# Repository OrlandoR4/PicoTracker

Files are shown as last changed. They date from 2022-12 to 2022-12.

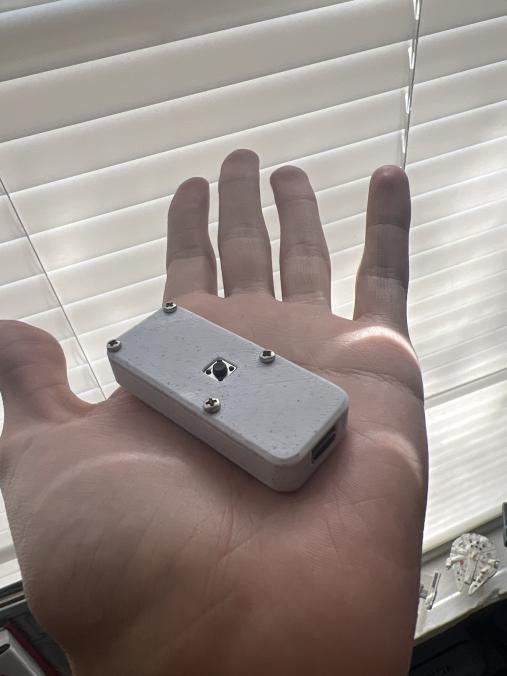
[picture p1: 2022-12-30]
example/Built device.jpg

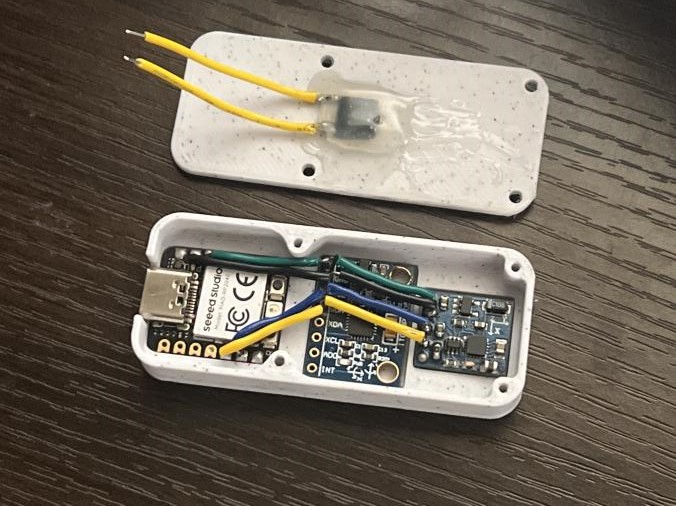
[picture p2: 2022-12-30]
example/Internals.jpg

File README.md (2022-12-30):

### VERSION 2.0

# HATIRE-ENABLED HEAD TRACKER FOR OPENTRACK

This program uses the **XIAO RP2040 microcontroller**,
**MPU6050** Inertial Measurement Unit, and the **QMC5883L**
magnetometer to estimate orientation and output HATIRE
data for OpenTrack

Uses a single push button for calibration and resetting (with an internal pull up from the microcontroller)

Customize the code as its fit to you and install the necessary dependencies

If the sensors or microcontroller above aren't being used
major code modification will be necessary, please refer to the comments below

***

### For the orientation to work

**Configure your vectors like this (Right Hand Rule):**

(X, Y, Z) = Roll Pitch Yaw

X : Forwards,
Y : Rightwards,
Z : Downwards
***
## USAGE

**IN-GAME:**

* Press the button to reset the euler angles, do this once
before as you play and as you see fit

**CALIBRATION:**

* Place the device where you intend to use it, for example your headphones
* Ensure the device is square and aligned with your vectors, X or FORWARDS has to your monitor and Z should be pointing DOWN

* The device is sensitive to magnetic fields and metal, so make sure you calibrate in the same conditions and position that you will be when playing

* For these first steps ensure the device is still, DO NOT ROTATE OR MOVE IT

* To calibrate the device hold the button as you connect the USB cable

* The LED will flash quickly as it calibrates the gyroscope

* Then slower as it calibrates the accelerometers

* When the LED turns off or partially off, its time to calibrate the magnetometer
  
* You can now move the device, spin the device around on ALL AXES, pretend to paint a sphere from the inside while you roll the device as well

The calibration settings will be stored on the EEPROM of your microcontroller so no new calibration has to be done every time you plug in the device

The device will slowly blink the LED when the calibration is done
You can now use the device with HATIRE and OpenTrack

Configure the axes, mappings, and filter settings as you see fit

If the raw sensor data on OpenTrack seems erroneous or undersirable,
or you set up the device on new headphones or similar,
please re-do the calibration as many times as needed

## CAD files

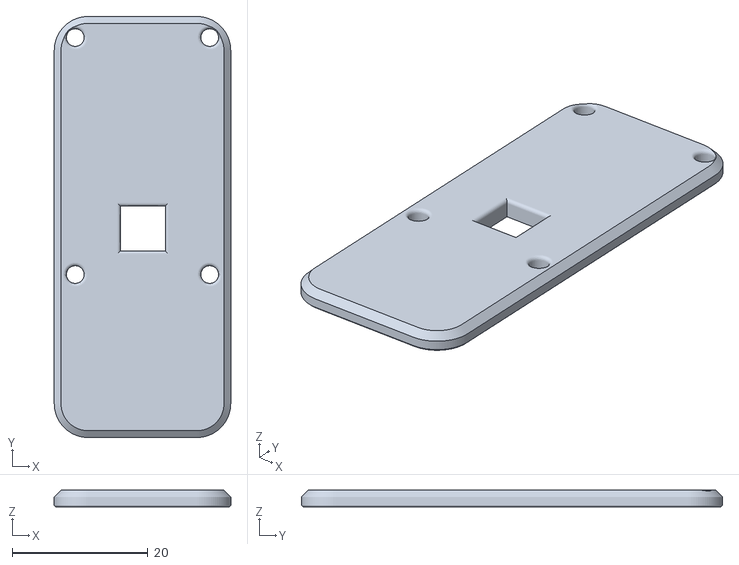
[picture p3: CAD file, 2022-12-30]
prints/Top.stl
26.0 x 62.0 x 2.50

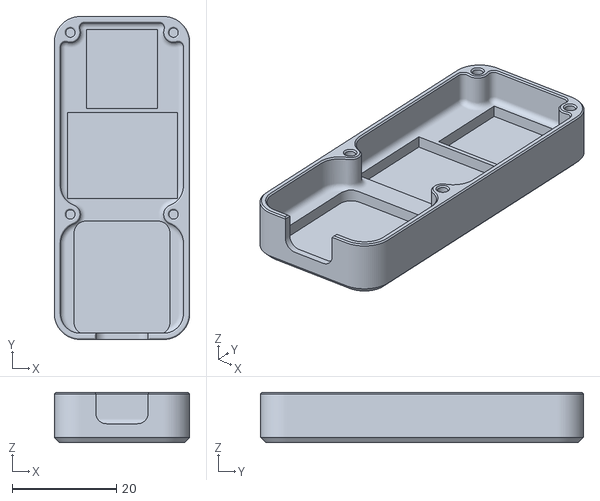
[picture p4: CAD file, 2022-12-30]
prints/Base.stl
26.0 x 62.0 x 9.60

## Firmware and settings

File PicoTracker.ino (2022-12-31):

/*
 * #################################
 * HATIRE HEAD TRACKER FOR OPENTRACK
 * #################################
 * 
 * This program uses the Rpi Pico microcontroller,
 * MPU6050 Inertial Measurement Unit, and the QMC5883L
 * magnetometer to estimate orientation and output HATIRE
 * data for OpenTrack
 * 
 * Customize the code as its fit to you and install the necessary dependencies
 * 
 * If the sensors or microcontroller above aren't being used
 * major code modification will be necessary, please refer to the comments below
 * 
 * LICENSE
 * 
 * O. Rangel Morales
 * (GitHub: OrlandoR4)
 * MIT license, all text above must be included in any redistribution
 */

#include <Arduino.h>

#include <Wire.h>
#include <EEPROM.h>
#include "Quaternion.h"

#define Wire Wire1

#include "QMC5883LCompass.h"
#include <Adafruit_Sensor.h>
#include <Adafruit_MPU6050.h>

// Inertial Measurements
Vector3 acceleration_body;
Vector3 angular_velocity;
Vector3 magnetic_flux;

// Orientation
Quaternion true_orientation;
Quaternion offset_quaternion;
Quaternion orientation;

Vector3 euler_angles;
Vector3 acceleration_inertial;

// Calibration Variables
Vector3 offset_angular_velocity;
Vector3 offset_acceleration_body;
Vector3 offset_magnetic_flux;
Vector3 scalar_magnetic_flux(1, 1, 1);

// Orientation Filter
const float orientation_filter_frequency = 200;
const float accelerometer_correction_gain = 0.01;
const float magnetometer_correction_gain = 0.01;

// EEPROM per 32 Bytes
// 0 -> 2  : gyroscopic offsets
// 3 -> 5  : acceleration offsets
// 6 -> 8  : magnetic offsets
// 9 -> 11 : magnetic scalar
union data_union
{
  struct data_struct
  {
    float off_x_g;
    float off_y_g;
    float off_z_g;

    float off_x_a;
    float off_y_a;
    float off_z_a;

    float off_x_m;
    float off_y_m;
    float off_z_m;

    float scal_x_m;
    float scal_y_m;
    float scal_z_m;
  } calibration_struct;
  char calibration_string[sizeof(data_struct)];
} calibration_data;

// HATIRE
struct  {
  int16_t  Begin;           // 2  Begin
  uint16_t Cpt;             // 2  Computer frame or Code
  float    euler_angles[3]; // 12 [Roll, Pitch, Yaw] Euler angles in degrees
  float    position[3];     // 12 [x, y, z] Position in meters
  int16_t  End;             // 2  End
} hatire;

/**
 * Customize your sensors here!
 * 
 * Change the code to fit your custom sensors if you're not
 * using the QMC5883L and the MPU6050
 */
QMC5883LCompass QMC_5883;
Adafruit_MPU6050 MPU_6050;
/**
 * Customize your pin settings here!
 */
const int LED = 25;
const int BUTTON = A0;
const int SCL_PIN = 7;
const int SDA_PIN = 6;
/**
 * Customize your sensor readings here!
 * 
 * Change the axes of the sensors depending on how your sensors are oriented
 * 
 * Change the code to fit your custom sensors if you're not
 * using the QMC5883L and the MPU6050
 */
void read_sensors()
{
  // Read IMU data
  sensors_event_t a, g, temp;
  MPU_6050.getEvent(&a, &g, &temp);
  // Radians per second
  angular_velocity.x =  g.gyro.y;
  angular_velocity.y =  g.gyro.x;
  angular_velocity.z = -g.gyro.z;
  // Meters per second squared
  acceleration_body.x =  a.acceleration.y;
  acceleration_body.y =  a.acceleration.x;
  acceleration_body.z = -a.acceleration.z;

  // Read Magnetometer Data
  QMC_5883.read();
  // Micro-teslas
  magnetic_flux.x = -QMC_5883.getX();
  magnetic_flux.y =  QMC_5883.getY();
  magnetic_flux.z = -QMC_5883.getZ();
}
// LED blink
void blink_LED(uint32_t frequency_ms)
{
  static bool state_LED;
  static uint32_t previous_time = 0;

  if (millis() - previous_time > frequency_ms)
  {
    previous_time = millis();

    state_LED = !state_LED;
    digitalWrite(LED, state_LED);
  }
}
// Error message to display to the serial monitor, LED blinks
void error_message(const String error_message_string)
{
  blink_LED(250);

  static uint32_t previous_time = 0;
  if (millis() - previous_time > 250)
  {
    previous_time = millis();

    Serial.println(error_message_string);
  }
}
// Gyroscope Calibration
void calibrate_gyroscope(uint32_t timer_trigger_ms)
{
  // Reset offsets
  offset_angular_velocity *= 0;

  // Track time
  uint32_t time = millis();
  uint32_t previous_time = millis();
  uint32_t delta_time = 0;
  uint32_t calibration_timer = 0;

  while (true)
  {
    // Timekeeping
    previous_time = time;
    time = millis();
    delta_time = time - previous_time;

    // Blink LED for indication
    blink_LED(50);

    // Get IMU data
    read_sensors();

    // Only log data if the gyroscope isn't being moved a lot
    if (angular_velocity.get_magnitude() < 15.f * DEG_TO_RAD)
    {
      // Add time
      calibration_timer += delta_time;

      // Add bias to the offset
      offset_angular_velocity += angular_velocity * float(delta_time);

      if (calibration_timer > timer_trigger_ms)
      {
        // Average the measurements over the elapsed time
        offset_angular_velocity /= float(calibration_timer);

        break;
      }
    }
  }

  return;
}
// Accelerometer Calibration
void calibrate_accelerometer(uint32_t timer_trigger_ms)
{
  // Reset offsets
  offset_acceleration_body *= 0;

  // Track time
  uint32_t time = millis();
  uint32_t previous_time = millis();
  uint32_t delta_time = 0;
  uint32_t calibration_timer = 0;

  while (true)
  {
    // Timekeeping
    previous_time = time;
    time = millis();
    delta_time = time - previous_time;

    // Blink LED for indication
    blink_LED(150);

    // Get IMU data
    read_sensors();

    // Only log data if the accelerometer isn't being moved a lot
    if (acceleration_body.get_magnitude() < 15)
    {
      // Add time
      calibration_timer += delta_time;

      // Add bias to the offset
      offset_acceleration_body += acceleration_body * float(delta_time);

      if (calibration_timer > timer_trigger_ms)
      {
        // Average the measurements over the elapsed time
        offset_acceleration_body /= float(calibration_timer);

        // Add gravity offset
        offset_acceleration_body.z += 9.8066f;

        break;
      }
    }
  }

  return;
}
// Magnetometer Calibration
void calibrate_magnetometer(uint32_t timer_trigger_ms)
{
  // Reset offsets
  offset_magnetic_flux = Vector3(0, 0, 0);
  scalar_magnetic_flux = Vector3(1, 1, 1);

  // Track time
  uint32_t time = millis();
  uint32_t previous_time = millis();
  uint32_t delta_time = 0;
  uint32_t calibration_timer = 0;

  // Magnetometer calibration variables
  float min[3] = { 1e9,  1e9,  1e9};
  float max[3] = {-1e9, -1e9, -1e9};

  while (true)
  {
    // Timekeeping
    previous_time = time;
    time = millis();
    delta_time = time - previous_time;

    // Get magnetometer data
    read_sensors();

    // Track if the acceleration has changed
    bool changed = false;

    if (magnetic_flux.x > max[0]) { max[0] = magnetic_flux.x; changed = true; }
    if (magnetic_flux.y > max[1]) { max[1] = magnetic_flux.y; changed = true; }
    if (magnetic_flux.z > max[2]) { max[2] = magnetic_flux.z; changed = true; }

    if (magnetic_flux.x < min[0]) { min[0] = magnetic_flux.x; changed = true; }
    if (magnetic_flux.y < min[1]) { min[1] = magnetic_flux.y; changed = true; }
    if (magnetic_flux.z < min[2]) { min[2] = magnetic_flux.z; changed = true; }

    if (!changed)
    {
      // Turn off LED for indication
      digitalWrite(LED, HIGH);

      // Add time
      calibration_timer += delta_time;
    }else{
      // Blink LED for indication
      blink_LED(50);

      // Reset time
      calibration_timer = 0;
    }

    // Exit if timer is satisfied
    if (calibration_timer > timer_trigger_ms)
      break;
  }
  
  const float ideal_halfscale = 10000.f;  

  scalar_magnetic_flux.x = (2.0f * ideal_halfscale) / (max[0] - min[0]);
  scalar_magnetic_flux.y = (2.0f * ideal_halfscale) / (max[1] - min[1]);
  scalar_magnetic_flux.z = (2.0f * ideal_halfscale) / (max[2] - min[2]);

  offset_magnetic_flux.x = max[0] - ((max[0] - min[0]) / 2);
  offset_magnetic_flux.y = max[1] - ((max[1] - min[1]) / 2);
  offset_magnetic_flux.z = max[2] - ((max[2] - min[2]) / 2);

  return;
}
// Update attitude
void update_attitude()
{
  static uint32_t previous_time = 0;

  if (millis() - previous_time > uint32_t((1000.f)/(orientation_filter_frequency)))
  {
    // Timekeeping
    float delta_time_s = float(millis() - previous_time)*0.001f;
    previous_time = millis();

    // Update sensor data
    read_sensors();

    angular_velocity -= offset_angular_velocity;
    acceleration_body -= offset_acceleration_body;
    magnetic_flux = (magnetic_flux - offset_magnetic_flux) * scalar_magnetic_flux;

    // Update filter
    Vector3 ori_acceleration_inertial = true_orientation.rotate_vector(acceleration_body);

    true_orientation.update_with_rates(delta_time_s, angular_velocity);
    true_orientation.update_with_accel(ori_acceleration_inertial, Vector3(0, 0, -1), accelerometer_correction_gain);
    true_orientation.update_with_mag(magnetic_flux, acceleration_body, Vector3(0, 1, 0), Quaternion(1, 0, 0, 0), magnetometer_correction_gain);

    // Update output quaternion
    orientation = offset_quaternion * true_orientation;

    // Update inertial acceleration
    acceleration_inertial = orientation.rotate_vector(acceleration_body);
    acceleration_inertial.z += 9.8066f;
    
    // Update euler angles
    euler_angles = orientation.quaternion_to_euler();
  }
}
/**
 * Customize your initialization code here!
 * 
 * Change the sensors to your desired sensors or leave as is if you're using the
 * QMC5883L and the MPU6050
 * 
 * Change the pin configuration as well if you're not using a Raspberry Pi Pico
 */
void setup()
{
  // Initialize Serial Port
  Serial.begin(115200);

  // Begin EEPROM
  EEPROM.begin(256);

  // Initialize I2C Pins
  Wire.setSCL(SCL_PIN);
  Wire.setSDA(SDA_PIN);
  Wire.begin();

  // Initialize pins
  pinMode(LED, OUTPUT);
  pinMode(BUTTON, INPUT_PULLUP);

  pinMode(16, OUTPUT); digitalWrite(16, HIGH);
  pinMode(17, OUTPUT); digitalWrite(17, HIGH);

  // Initialize QMC5883
  QMC_5883.init();
  Wire.beginTransmission(0x0D);
  if (Wire.endTransmission() > 0) { error_message("Failed to initialize QMC5883"); }

  // Initialize MPU6050
  while (!MPU_6050.begin())
    error_message("Failed to initialize MPU6050");

  // Configure QMC5883
  QMC_5883.setMode(0x01, 0x0C, 0x10, 0x00);

  // Configure MPU6050
  MPU_6050.setAccelerometerRange(MPU6050_RANGE_4_G);
  MPU_6050.setGyroRange(MPU6050_RANGE_1000_DEG);
  MPU_6050.setFilterBandwidth(MPU6050_BAND_44_HZ);
  
  // Setup HATIRE
  hatire.Begin = 0xAAAA;
  hatire.Cpt = 0;
  hatire.End = 0x5555;

  // Initialization Miscellaneous
  Serial.println("Successful Initialization!");

  // Optional Calibration
  if (!digitalRead(BUTTON))
  {
    // Calibrate Gyroscope
    Serial.println("Calibrating gyroscope, do not move the sensor...");
    calibrate_gyroscope(5000);

    // Calibrate Accelerometer
    Serial.println("Calibrating gyroscope, do not move the sensor...");
    calibrate_accelerometer(5000);
    
    // Calibrate Magnetometer
    Serial.println("Calibrating magnetometer, gently spin around the sensor on all axis...");
    calibrate_magnetometer(10000);

    // Set values
    calibration_data.calibration_struct.off_x_g  = offset_angular_velocity.x;
    calibration_data.calibration_struct.off_y_g  = offset_angular_velocity.y;
    calibration_data.calibration_struct.off_z_g  = offset_angular_velocity.z;
    calibration_data.calibration_struct.off_x_a  = offset_acceleration_body.x;
    calibration_data.calibration_struct.off_y_a  = offset_acceleration_body.y;
    calibration_data.calibration_struct.off_z_a  = offset_acceleration_body.z;
    calibration_data.calibration_struct.off_x_m  = offset_magnetic_flux.x;
    calibration_data.calibration_struct.off_y_m  = offset_magnetic_flux.y;
    calibration_data.calibration_struct.off_z_m  = offset_magnetic_flux.z;
    calibration_data.calibration_struct.scal_x_m = scalar_magnetic_flux.x;
    calibration_data.calibration_struct.scal_y_m = scalar_magnetic_flux.y;
    calibration_data.calibration_struct.scal_z_m = scalar_magnetic_flux.z;

    // Store Calibration
    EEPROM.put(0, calibration_data.calibration_string);
    EEPROM.commit();
  }
  else
  {
    EEPROM.get(0, calibration_data.calibration_string);

    // Set values
    offset_angular_velocity.x = calibration_data.calibration_struct.off_x_g ;
    offset_angular_velocity.y = calibration_data.calibration_struct.off_y_g ;
    offset_angular_velocity.z = calibration_data.calibration_struct.off_z_g ;
    offset_acceleration_body.x = calibration_data.calibration_struct.off_x_a ;
    offset_acceleration_body.y = calibration_data.calibration_struct.off_y_a ;
    offset_acceleration_body.z = calibration_data.calibration_struct.off_z_a ;
    offset_magnetic_flux.x = calibration_data.calibration_struct.off_x_m ;
    offset_magnetic_flux.y = calibration_data.calibration_struct.off_y_m ;
    offset_magnetic_flux.z = calibration_data.calibration_struct.off_z_m ;
    scalar_magnetic_flux.x = calibration_data.calibration_struct.scal_x_m;
    scalar_magnetic_flux.y = calibration_data.calibration_struct.scal_y_m;
    scalar_magnetic_flux.z = calibration_data.calibration_struct.scal_z_m;
  }

  // Begin Loop
  digitalWrite(LED, LOW);
  delay(1000);
}
// Loop
void loop()
{
  // Update Orientation
  update_attitude();
  // read_sensors();

  // Zero Orientation until released
  if (!digitalRead(BUTTON))
  {
    offset_quaternion = true_orientation.conjugate();
    blink_LED(100);
  }
  else
  {
    blink_LED(1000);
  }
  
  // Set hatire values
  hatire.euler_angles[0] = euler_angles.x * RAD_TO_DEG;
  hatire.euler_angles[1] = euler_angles.y * RAD_TO_DEG;
  hatire.euler_angles[2] = euler_angles.z * RAD_TO_DEG;

  hatire.position[0] = euler_angles.x * RAD_TO_DEG / 4.5f;
  hatire.position[1] = euler_angles.y * RAD_TO_DEG / 4.5f;
  hatire.position[2] = euler_angles.z * RAD_TO_DEG / 4.5f;

  // Write to hatire
  Serial.write((byte*)&hatire,30);
  hatire.Cpt++;
  if (hatire.Cpt > 999) 
    hatire.Cpt=0;

  // Debug
  /*Serial.print(angular_velocity.x, 1); Serial.print(", ");
  Serial.print(angular_velocity.y, 1); Serial.print(", ");
  Serial.print(angular_velocity.z, 1); Serial.print(", ");

  Serial.print(acceleration_body.x, 1); Serial.print(", ");
  Serial.print(acceleration_body.y, 1); Serial.print(", ");
  Serial.print(acceleration_body.z, 1); Serial.print(", ");

  Serial.print(magnetic_flux.x, 1); Serial.print(", ");
  Serial.print(magnetic_flux.y, 1); Serial.print(", ");
  Serial.print(magnetic_flux.z, 1); Serial.print(", ");

  Serial.print(euler_angles.x * RAD_TO_DEG, 1); Serial.print(", ");
  Serial.print(euler_angles.y * RAD_TO_DEG, 1); Serial.print(", ");
  Serial.print(euler_angles.z * RAD_TO_DEG, 1); Serial.println("");*/
  
  // Visualizer
  /*Serial.print("Orientation: ");
  Serial.print(euler_angles.z * RAD_TO_DEG);
  Serial.print(" ");
  Serial.print(euler_angles.y * RAD_TO_DEG);
  Serial.print(" ");
  Serial.println(euler_angles.x * RAD_TO_DEG);*/
}

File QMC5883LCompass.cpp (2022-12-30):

/*
===============================================================================================================
QMC5883LCompass.h
Library for using QMC5583L series chip boards as a compass.
Learn more at [https://github.com/mprograms/QMC5883LCompass]

Supports:

- Getting values of XYZ axis.
- Calculating Azimuth.
- Getting 16 point Azimuth bearing direction (0 - 15).
- Getting 16 point Azimuth bearing Names (N, NNE, NE, ENE, E, ESE, SE, SSE, S, SSW, SW, WSW, W, WNW, NW, NNW)
- Smoothing of XYZ readings via rolling averaging and min / max removal.
- Optional chipset modes (see below)

===============================================================================================================

v1.0 - June 13, 2019
Written by MRPrograms 
Github: [https://github.com/mprograms/]

Release under the GNU General Public License v3
[https://www.gnu.org/licenses/gpl-3.0.en.html]

===============================================================================================================



FROM QST QMC5883L Datasheet [https://nettigo.pl/attachments/440]
-----------------------------------------------
 MODE CONTROL (MODE)
	Standby			0x00
	Continuous		0x01

OUTPUT DATA RATE (ODR)
	10Hz        	0x00
	50Hz        	0x04
	100Hz       	0x08
	200Hz       	0x0C

FULL SCALE (RNG)
	2G          	0x00
	8G          	0x10

OVER SAMPLE RATIO (OSR)
	512         	0x00
	256         	0x40
	128         	0x80
	64          	0xC0 
  
*/



#include "Arduino.h"
#include "QMC5883LCompass.h"
#include <Wire.h>
#define Wire Wire1
QMC5883LCompass::QMC5883LCompass() {
}


/**
	INIT
	Initialize Chip - This needs to be called in the sketch setup() function.
	
	@since v0.1;
**/
void QMC5883LCompass::init(){
	Wire.begin();
	_writeReg(0x0B,0x01);
	setMode(0x01,0x0C,0x10,0X00);
}


/**
	SET ADDRESS
	Set the I2C Address of the chip. This needs to be called in the sketch setup() function.
	
	@since v0.1;
**/
// Set I2C Address if different then default.
void QMC5883LCompass::setADDR(byte b){
	_ADDR = b;
}




/**
	REGISTER
	Write the register to the chip.
	
	@since v0.1;
**/
// Write register values to chip
void QMC5883LCompass::_writeReg(byte r, byte v){
	Wire.beginTransmission(_ADDR);
	Wire.write(r);
	Wire.write(v);
	Wire.endTransmission();
}


/**
	CHIP MODE
	Set the chip mode.
	
	@since v0.1;
**/
// Set chip mode
void QMC5883LCompass::setMode(byte mode, byte odr, byte rng, byte osr){
	_writeReg(0x09,mode|odr|rng|osr);
}


/**
	RESET
	Reset the chip.
	
	@since v0.1;
**/
// Reset the chip
void QMC5883LCompass::setReset(){
	_writeReg(0x0A,0x80);
}

// 1 = Basic 2 = Advanced
void QMC5883LCompass::setSmoothing(byte steps, bool adv){
	_smoothUse = true;
	_smoothSteps = ( steps > 10) ? 10 : steps;
	_smoothAdvanced = (adv == true) ? true : false;
}

/**
    SET CALIBRATION
	Set calibration values for more accurate readings
		
	@author Claus Näveke - TheNitek [https://github.com/TheNitek]
	
	@since v1.1.0
**/
void QMC5883LCompass::setCalibration(int x_min, int x_max, int y_min, int y_max, int z_min, int z_max){
	_calibrationUse = true;

	_vCalibration[0][0] = x_min;
	_vCalibration[0][1] = x_max;
	_vCalibration[1][0] = y_min;
	_vCalibration[1][1] = y_max;
	_vCalibration[2][0] = z_min;
	_vCalibration[2][1] = z_max;
}



/**
	READ
	Read the XYZ axis and save the values in an array.
	
	@since v0.1;
**/
void QMC5883LCompass::read(){
	Wire.beginTransmission(_ADDR);
	Wire.write(0x00);
	int err = Wire.endTransmission();
	if (!err) {
		Wire.requestFrom(_ADDR, (byte)6);
		_vRaw[0] = (int)(int16_t)(Wire.read() | Wire.read() << 8);
		_vRaw[1] = (int)(int16_t)(Wire.read() | Wire.read() << 8);
		_vRaw[2] = (int)(int16_t)(Wire.read() | Wire.read() << 8);

		if ( _calibrationUse ) {
			_applyCalibration();
		}
		
		if ( _smoothUse ) {
			_smoothing();
		}
		
		//byte overflow = Wire.read() & 0x02;
		//return overflow << 2;
	}
}

/**
    APPLY CALIBRATION
	This function uses the calibration data provided via @see setCalibration() to calculate more
	accurate readings
	
	@author Claus Näveke - TheNitek [https://github.com/TheNitek]
	
	Based on this awesome article:
	https://appelsiini.net/2018/calibrate-magnetometer/
	
	@since v1.1.0
	
**/
void QMC5883LCompass::_applyCalibration(){
	int x_offset = (_vCalibration[0][0] + _vCalibration[0][1])/2;
	int y_offset = (_vCalibration[1][0] + _vCalibration[1][1])/2;
	int z_offset = (_vCalibration[2][0] + _vCalibration[2][1])/2;
	int x_avg_delta = (_vCalibration[0][1] - _vCalibration[0][0])/2;
	int y_avg_delta = (_vCalibration[1][1] - _vCalibration[1][0])/2;
	int z_avg_delta = (_vCalibration[2][1] - _vCalibration[2][0])/2;

	int avg_delta = (x_avg_delta + y_avg_delta + z_avg_delta) / 3;

	float x_scale = (float)avg_delta / x_avg_delta;
	float y_scale = (float)avg_delta / y_avg_delta;
	float z_scale = (float)avg_delta / z_avg_delta;

	_vCalibrated[0] = (_vRaw[0] - x_offset) * x_scale;
	_vCalibrated[1] = (_vRaw[1] - y_offset) * y_scale;
	_vCalibrated[2] = (_vRaw[2] - z_offset) * z_scale;
}


/**
	SMOOTH OUTPUT
	This function smooths the output for the XYZ axis. Depending on the options set in
	@see setSmoothing(), we can run multiple methods of smoothing the sensor readings.
	
	First we store (n) samples of sensor readings for each axis and store them in a rolling array.
	As each new sensor reading comes in we replace it with a new reading. Then we average the total
	of all (n) readings.
	
	Advanced Smoothing
	If you turn advanced smoothing on, we will select the min and max values from our array
	of (n) samples. We then subtract both the min and max from the total and average the total of all
	(n - 2) readings.
	
	NOTE: This function does several calculations and can cause your sketch to run slower.
	
	@since v0.3;
**/
void QMC5883LCompass::_smoothing(){
	byte max = 0;
	byte min = 0;
	
	if ( _vScan > _smoothSteps - 1 ) { _vScan = 0; }
	
	for ( int i = 0; i < 3; i++ ) {
		if ( _vTotals[i] != 0 ) {
			_vTotals[i] = _vTotals[i] - _vHistory[_vScan][i];
		}
		_vHistory[_vScan][i] = ( _calibrationUse ) ? _vCalibrated[i] : _vRaw[i];
		_vTotals[i] = _vTotals[i] + _vHistory[_vScan][i];
		
		if ( _smoothAdvanced ) {
			max = 0;
			for (int j = 0; j < _smoothSteps - 1; j++) {
				max = ( _vHistory[j][i] > _vHistory[max][i] ) ? j : max;
			}
			
			min = 0;
			for (int k = 0; k < _smoothSteps - 1; k++) {
				min = ( _vHistory[k][i] < _vHistory[min][i] ) ? k : min;
			}
					
			_vSmooth[i] = ( _vTotals[i] - (_vHistory[max][i] + _vHistory[min][i]) ) / (_smoothSteps - 2);
		} else {
			_vSmooth[i] = _vTotals[i]  / _smoothSteps;
		}
	}
	
	_vScan++;
}


/**
	GET X AXIS
	Read the X axis
	
	@since v0.1;
	@return int x axis
**/
int QMC5883LCompass::getX(){
	return _get(0);
}


/**
	GET Y AXIS
	Read the Y axis
	
	@since v0.1;
	@return int y axis
**/
int QMC5883LCompass::getY(){
	return _get(1);
}


/**
	GET Z AXIS
	Read the Z axis
	
	@since v0.1;
	@return int z axis
**/
int QMC5883LCompass::getZ(){
	return _get(2);
}
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

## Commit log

2022-12-30 Version 2.0 XIAO overhaul
    [Base.stl, Top.stl]
2022-12-30 Changed brackets to quotations on qmc
